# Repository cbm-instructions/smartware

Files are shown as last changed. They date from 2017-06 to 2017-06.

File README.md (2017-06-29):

# Smartware
"Challenge Based Making" an der Hochschule Mannheim im Sommersemester 2017. Betreut von Prof. Thomas Smits und Prof. Kirstin Kohler.
Die Projektarbeit dieses Kurses fand in zwei Pfasen statt: Dem Design Thinking und der Umsetzung.

# Übersicht
* [POV](#pov)
* [Lösungsansatz/Prototyp](#lösungsansatzprototyp)
	* [Konzept](#konzept)
* [(Bau-)Anleitung](#bau-anleitung)
	* [Laserschranke](#laserschranke)
		* [Schranken](#schranken)
		* [Elektronik](#elektronik)
			* [Schaltplan](#schaltplan)
			* [Code](#code)
	* [Webkomponente](#webkomponente)
		* [Frontend](#frontend)
		* [Backend](#backend)
	* [Messstation](#messstation)
		* [Schaltplan](#schaltplan-1)
		* [Code](#code-1)
* [Fazit](#fazit)

## POV
_Wie können wir Stundenten helfen freie Räume zu finden, um dort in Ruhe zu lernen/arbeiten?_

## Lösungsansatz/Prototyp
Da es an unserer Hochschule keine zentrale Übersicht über aktuelle Raumbelegungen gibt und somit die Suche nach freien Hörsälen zum (gemeinsamen) Lernen und Arbeiten mitunter zeitaufwändig werden kann, wollten wir ein System entwickeln, mit dem Studenten überall und jederzeit geeignete Lernräume finden können.
Zu diesem Zweck haben wir ein dreiteiliges System entwickelt, bestehend aus:
*	Türsystem
	*	Laserschranke
	*	Türsensor (Reed Switch)
*	Webkomponente
*	Messstation

Das Türsystem erfasst Aktivität im Eingangsbereich. Während die Laserschranke bei Unterbrechung des Laserstrahls durch dadurch laufende Menschen auslöst, registriert der Türsensor das Öffnen und Schließen der Tür. Die Messstation misst die Temperatur- und Luftfeuchtigkeit, um eine Bewertung der Luftqualität zu ermöglichen. All diese Daten fließen in der Webkomponente zusammen. Diese kann auf mobilen sowie Desktop-Geräten genutzt werden.

## (Bau-)Anleitung
### Laserschranke
Folgende Teile benötigt (Angaben in mm):
*   2 x OSB-Platte (800 x 150 x 10), als vertikale Halterung
*   2 x Holzplatte (350 x 150 x 30), aus möglichst schwerem Holz
*   2 x Dachlatte 360mm lang, als zusätzliche Befestigung -
	Diese müssen an beiden Enden auf Gehrung gesägt werden, sodass diese als Diagonale, zwischen Bodenplatte und vertikaler OSB-Platte, verwendet werden können.
*   2 x Dachlatte 70mm lang, als Spiegelhalterung -
	Diese müssen an einem Ende auf Gehrung gesägt werden, sodass die Spiegel im 45 Grad Winkel angebracht werden können.
*   2 x Schminkspiegel
*   Diverse Holzschrauben
*   Optional: Lack in beliebiger Farbe
*   Optional: Zur besseren Befestigung des Lasers, sowie des Fototransistors können Winkel eingesetzt werden.

Laserhalterung
Spiegelhalterung

Die Halterungen werden wie auf den Bildern zu sehen, zusammengeschraubt und falls gewünscht mit dem Lack besprüht. An der rechten Halterung ist ein Metwallwinkel zu sehen. Dieser wurde an der Oberseite mit etwas Klebeband isoliert, damit er keinen Kurzschluss erzeugt. Darauf wird später der Laser montiert. An der anderen Halterung muss dann die Spiegelhalterung (Dachlatten 70mm lang) angeschraubt werden. In einigem Abstand darunter wird die zweite Spiegelhalterung montiert. Die Spiegel werden dann mit Heißkleber befestigt. 
Funktionsweise: Der Laser schießt das Licht auf den oberen Spiegel, welcher das Licht auf den unteren reflektiert und anschließend wieder zurück zur anderen Halterung. An der Stelle, wo der Laser wieder auftrifft wird dann der Fototransistor befestigt, sodass erkannt werden kann, ob der Lichtstrahl unterbrochen wurde.

**Bitte beachten Sie:**
Diese Halterungen waren nur für den Prototyp gedacht. Wenn das System dauerhaft installiert werden soll, ist eine feste Verankerung (bspw. im Türrahmen) sinnvoll.

#### Elektronik
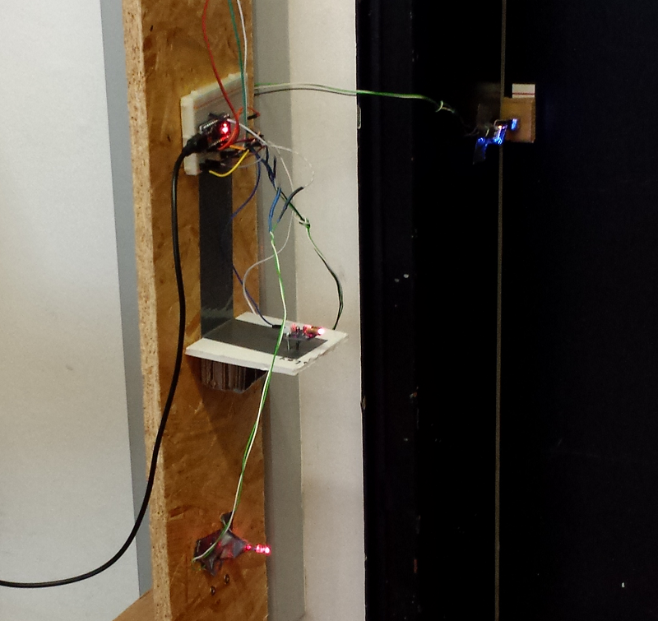
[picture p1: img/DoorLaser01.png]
DoorLaser


##### Schaltplan
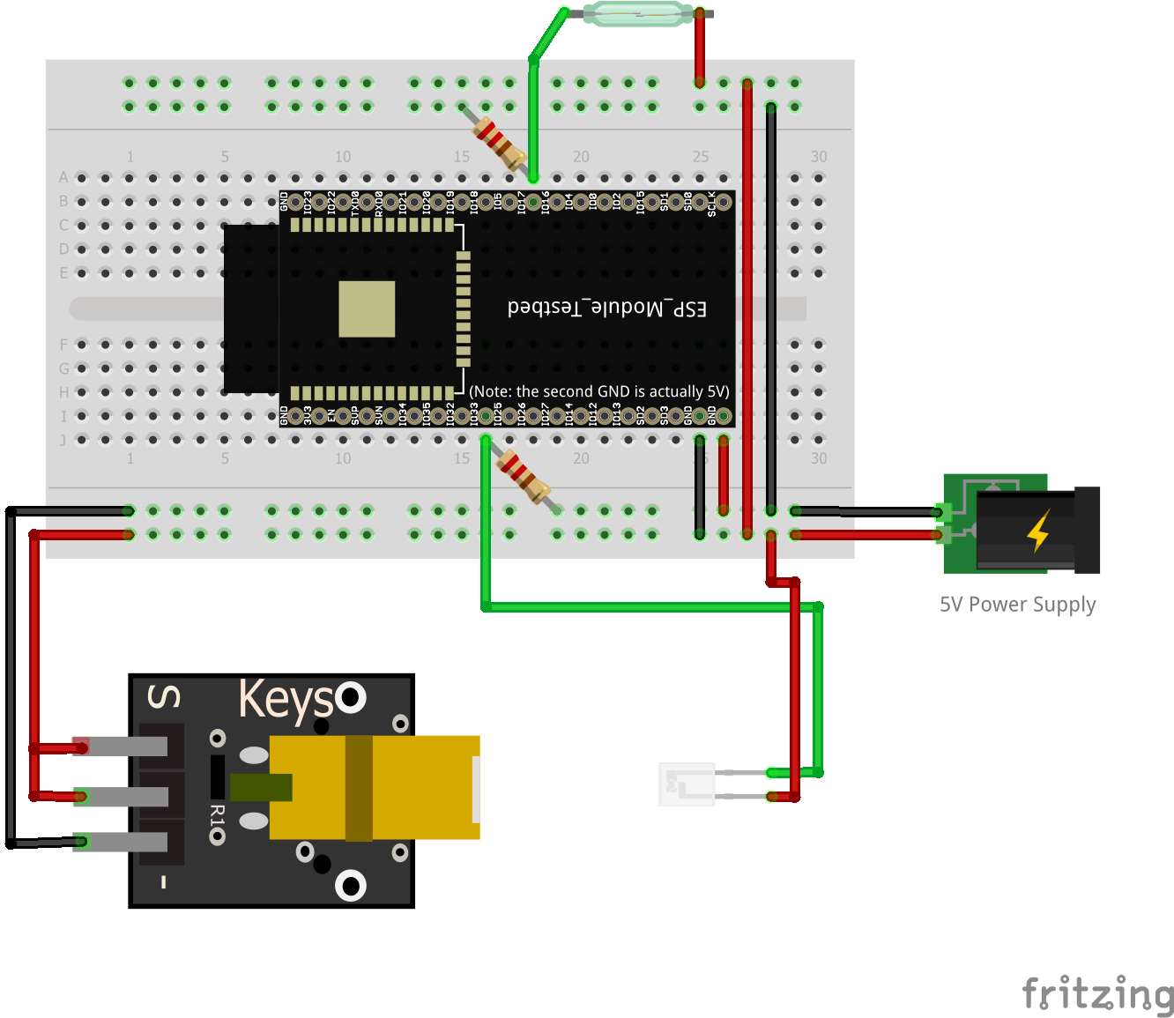
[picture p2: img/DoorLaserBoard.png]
Schaltplan DoorLaser

Bauteile:
* [ESP32](https://www.aliexpress.com/store/product/ESP32-Development-Board-WiFi-Bluetooth-Ultra-Low-Power-Consumption-Dual-Cores-ESP-32-ESP-32S/1983387_32799057508.html)
* 2x4.7k Ohm Widerstände
* [Phototransistor](https://www.conrad.de/de/fototransistor-5-mm-1100-nm-everlight-opto-pt331cpt333-3c-156408.html)
* [Laser](https://www.amazon.de/SunFounder-Transmitter-Sensor-Arduino-Raspberry/dp/B013QSHMSU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)
* Reed-Schalter
* Externe Stromversorgung 5V, min. 500mA

Der Reed-Schalter wird in diesem Beispiel an Pin 17, der Phototransistor an Pin 33 angeschlossen - Diese Pinbelegung wird auch im Code verwendet!

##### Code
Der Source-Code für die Laserschranke befindet sich unter [/src/DoorLaser/](/src/DoorLaser/). Die WLAN-Funktionalität inkl. Webserver sind [arduino-esp32 - SimpleWiFiServer](https://github.com/espressif/arduino-esp32/blob/master/libraries/WiFi/examples/SimpleWiFiServer/SimpleWiFiServer.ino) entnommen.

Wir haben, um das Hauptprogramm einfach zu halten, Klassen erstellt, die uns erlauben, bequem [digitale](/src/DoorLaser/DigitalListener.h) und [analoge](/src/DoorLaser/AnalogListener.h) Pins zu überwachen und deren Auslösungen zu zählen.

**Achtung:** Der ESP32 verwendet 12Bit ADCs, was bedeutet, dass analoge 5V-Signale anstatt des auf Arduinos üblichen Wertebereiches von 0-255 auf 0-4095 gemappt werden. 

### Webkomponente

#### Frontend

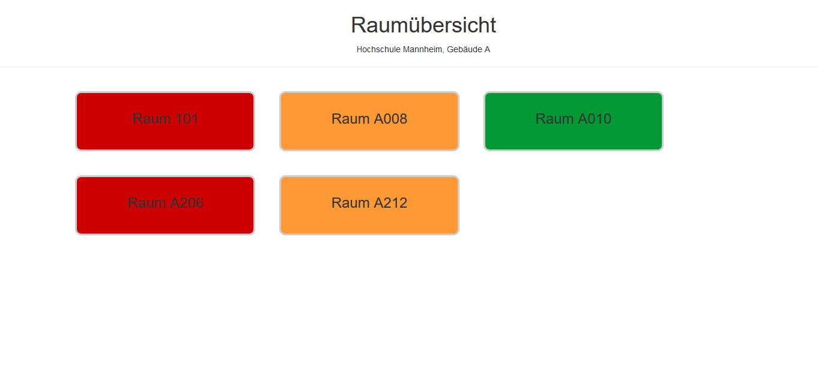
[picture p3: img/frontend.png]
Frontend

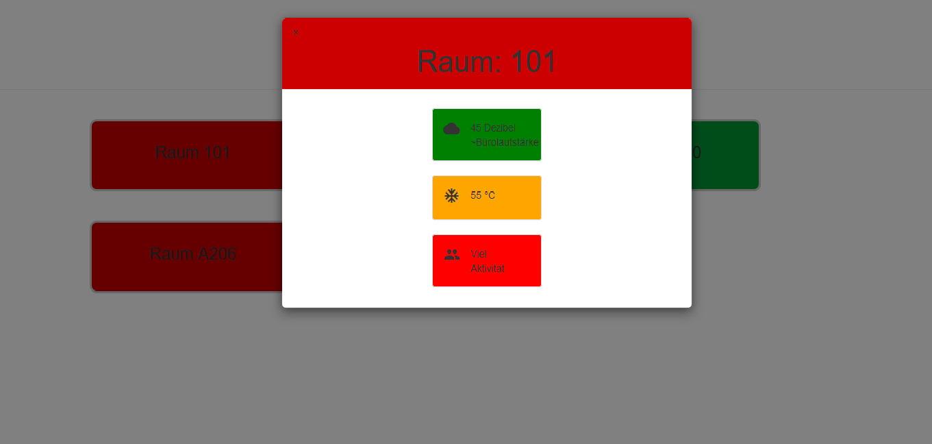
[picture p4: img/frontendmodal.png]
Frontend_Modal


Hier befindet sich die Benutzeroberfläche, welche mit HTML und CSS realisiert wird.
Außerdem sind Bootstrap und die Material-Icons von Google im Einsatz.

#### Backend

Hier befindet sich der Code zum betreiben des Backend Servers.
Geschrieben in node.js. Außerdem wird eine mysql Datenbank genutzt.

##### Setup und Installation des Backend und Frontend auf dem Raspberry Pi 

###### Benötigte Teile: 
	Raspberry Pi 3
	Micro SD Karte
	Router mit Internetverbindung (Internet nur zur Konfiguration)
	USB-Maus, USB Tastatur, Netzadapter Micro-USB, HDMI-fähiger Monitor

###### Installieren sie Raspbian auf dem Raspberry Pi.
	Eine einfache Schritt für Schritt Anleitung ist hier zu finden: 
	https://www.raspberrypi.org/learning/noobs-install/
	
###### Verbinden sie den Raspberry mit dem Internet.

###### Installieren der benötigten Software.
	Führen sie folgende Befehle in der Konsole aus:
	sudo apt-get update
	sudo apt-get upgrade

	Folgende Befehle installieren einen Datenbank-Server:
	sudo apt-get install mysql-server
	sudo apt-get install mysql-client
	sudo service mysql start;
	
	Installieren von git:
	sudo apt-get install git
	
	Installieren von nodejs:
	In einem leeren Verzeichnis:
	sudo git clone https://github.com/creationix/nvm.git.nvm

	Bitte folgenden Code an das Ende dieser Datei hängen: ~/.bashrc
	(Öffnen mit: sudo nano ~/.bashrc)
	export NVM_DIR="$HOME/.nvm"
	[ -s "$NVM_DIR/nvm.sh" ] && . "$NVM_DIR/nvm.sh"
	
	In der Konsole node und npm installieren:
	nvm install node
	nvm install npm

	prüfe installation mit:
	node --version 
	npm --version

###### Anlegen der Datenbank
	Einloggen in den Datenbank-Server mit:
	mysql -u „adminname“ -p -h localhost
	Anschließend das bei der Installation vergebene Passwort eingeben.
	
	In der mysql konsole (angezeigt durch mysql> folgende Befehle eingeben:
	
	create Database cbm;
	use cbm;
	
	create table rooms(room_id int NOT NULL auto_increment,
	name varchar(20) NOT NULL ,PRIMARY KEY(room_id));
	
	create Table sensors(sensor_id int NOT NULL auto_increment, 
	name varchar(20) NOT NULL, type varchar(20) NOT NULL,
	url varchar(200) NOT NULL, room_id int  NOT NULL, PRIMARY KEY(sensor_id), 
	FOREIGN KEY(room_id) references rooms(room_id));
	
	create table sensorvalues(value_id int NOT NULL auto_increment, 
	sensor_id int NOT NULL, value int NOT NULL, timest timestamp ,
	PRIMARY KEY(value_id),FOREIGN KEY(sensor_id) references sensors(sensor_id));

	Räume und Sensoren in die Datenbank eintragen:
	In der mysql Konsole:
	insert into rooms(name) values(„name“);
	
	Eingabe für jeden Raum wiederholen.

	Die zugeordneten Ids können nun mit folgender Eingabe angezeigt werden:
	Select * from rooms;

	Anschließend Sensoren in DB eintragen:
	Insert into sensors(room_id,name,type,url) values(„raum_id“,“name“,“typ“,“url“);
	
	Id muss richtigem Raum zugeordnet sein.
	Name ist frei wählbar.
	Typ muss entweder „temp“, „vol“ oder „light“ sein.
	In url muss die URL-Adresse eingetragen werden unter der der Sensor erreichbar ist.

###### Herunterladen und starten des Servers
	In leerem Ordner:
	sudo git clone https://github.com/cbm-instructions/smartware.git
	
	Die Datei mymysql.js öffnen und Adminname und Passwort des Datenbank-Servers eintragen.
	sudo nano src/WebComponent/backend/mymysql.js	

	Installieren der Abhängigkeiten:
	Im Verzeichnis src/webComonent ausführen:
	npm install 
	
	Nun kann der Code gestartet werden: 
	node main.js

	Der Server sollte nun unter seiner IP-Adresse auf Port 3000 erreichbar sein.
	(anzeigbar durch den Befehl ifconfig)

### Messstation
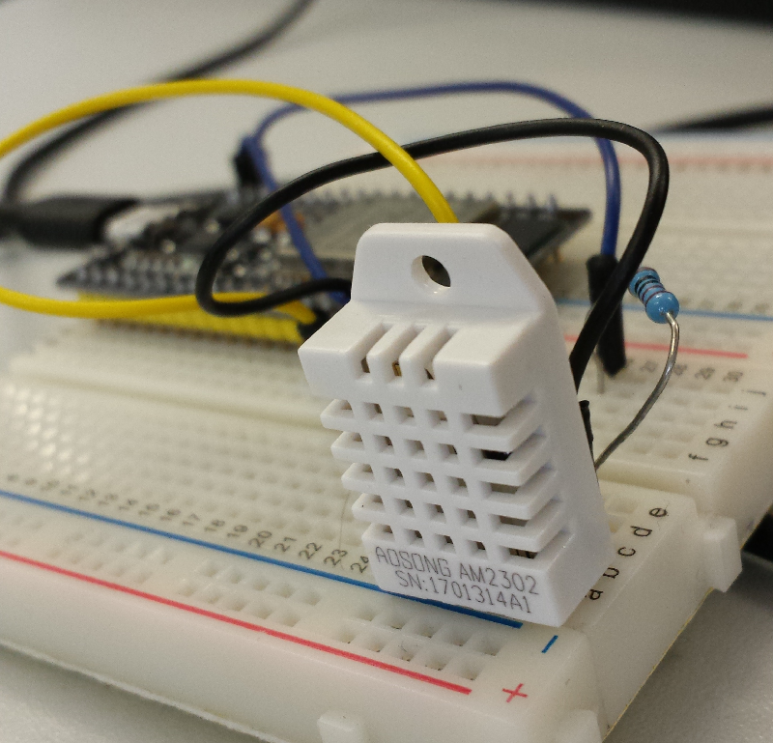
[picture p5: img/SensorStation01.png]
Messstation


#### Schaltplan
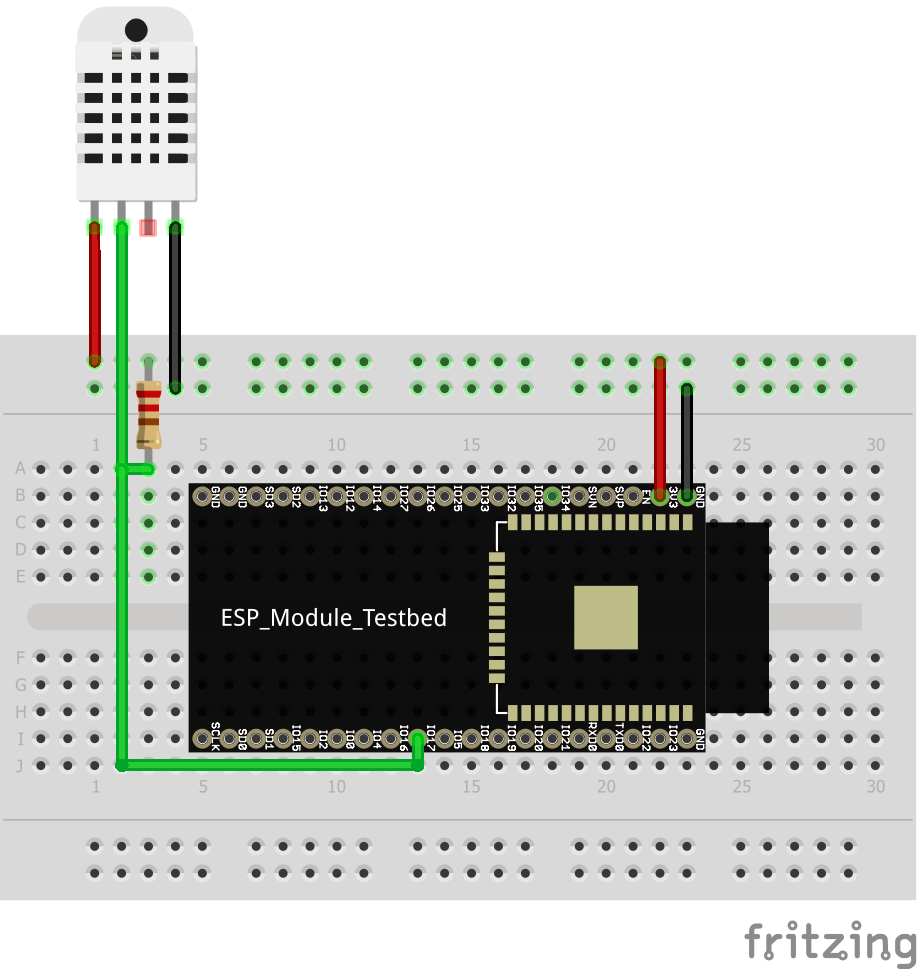
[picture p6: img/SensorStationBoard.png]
Schaltplan SensorStation

Bauteile:
* [ESP32](https://www.aliexpress.com/store/product/ESP32-Development-Board-WiFi-Bluetooth-Ultra-Low-Power-Consumption-Dual-Cores-ESP-32-ESP-32S/1983387_32799057508.html)
* 4.7k Ohm Widerstand
* [DHT22](https://www.aliexpress.com/item/50PCS-LOT-DHT22-AM2302-Digital-Temperature-and-Humidity-Sensor-DHT22-Free-shiping/1699337492.html)
* Micro-USB Kabel direkt am ESP32 für Stromversorgung

Pin 1 des DHT22 wird mit VCC, Pin 4 mit Masse und Pin 3 gar nicht verbunden. Pin 2 wird mit einem digitalen IO-Pin und über einen 4.7k Ohm Widerstand mit VCC verbunden.

#### Code
Der Source-Code für die Messstation befindet sich unter [/src/SensorStation/](/src/SensorStation/). Die WLAN-Funktionalität inkl. Webserver sind [arduino-esp32 - SimpleWiFiServer](https://github.com/espressif/arduino-esp32/blob/master/libraries/WiFi/examples/SimpleWiFiServer/SimpleWiFiServer.ino) entnommen. Backend und Frontend Code befinden sich unter
(src/WebComponent)

Wir hatten im Verlauf des Projekts Probleme damit, den DHT22 stabil durch den ESP32 anzusteuern. Deswegen haben wir uns dazu entschieden, fehlerhafte Messwerte zu ignorieren und nur die aktuellsten ([korrekten](/src/SensorStation/SensorStation.ino#L58)) Messwerte an das Backend weiterzureichen. Unsere Tests haben ergeben, dass ungefähr 80% aller Messungen fehlerhaft sind - Das kompensieren wir durch häufige (sekündliche) Messungen.

## Fazit

Die vorhandenen Daten lassen zwar bereits eine recht gute Bewertung der Raumverfügbarkeiten zu, jedoch würden Lautstärkemessungen die Qualität der Beurteilungen deutlich erhöhen. Aus Nutzerinterviews ging hervor, dass besonders die mobile Anwendung viel Anklang finden würde. Die Verwendung von WLAN als Kommunikationskanal resultierte in einfachen Installationen, verglichen mit kabelgebundenen Lösungen.

Bezüglich der Erweiterung des Sytems um Lautstärkemessungen muss recherchiert und erarbeitet werden, welche Mikrofone sich für diesen speziellen Anwendungsfall eignen. Für eine dauerhafte Installation der Türstation empfehlen wir die feste Integration der Bauteile in Türrahmen. Die Messstation hingegen kann frei im Raum platziert werden. Zur präziseren Bewertung der Luftqualität könnten verschiedene Bestandteile in der Raumluft gemessen werden.

Das positive Feedback der Nutzer, der unkomplizierte Zusammenbau und die einfache Installation der Komponenten legen die Umsetzung des Projekts an der Hochschule nahe. Ebenso bietet es viele Möglichkeiten zur Erweiterung und kann beispielsweise für Open Data über die Hochschule verwendet werden.

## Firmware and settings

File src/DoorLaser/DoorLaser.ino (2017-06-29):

/*
  Based on "WiFi Web Server LED Blink"-example 
*/

#include <WiFi.h>
#include "AnalogListener.h"
#include "DigitalListener.h"

#define PIN_DOOR 17
#define PIN_LASER 33
#define LASER_MIN 1024 //anstatt 300: ESP32 hat 12bit ADC!
#define LASER_MAX 4095 //anstatt 1024: ESP32 hat 12bit ADC

const char* ssid     = "YOUR_SSID";
const char* password = "YOUR_PASSWORD";

WiFiServer server(80);
AnalogListener laser(PIN_LASER, LASER_MIN, LASER_MAX);
DigitalListener door(PIN_DOOR, LOW);
char json[256];

void setup() {
    Serial.begin(115200);

    // We start by connecting to a WiFi network

    Serial.println();
    Serial.println();
    Serial.print("Connecting to ");
    Serial.println(ssid);

    WiFi.begin(ssid, password);

    while (WiFi.status() != WL_CONNECTED) {
        delay(500);
        Serial.print(".");
    }

    Serial.println("");
    Serial.println("WiFi connected");
    Serial.println("IP address: ");
    Serial.println(WiFi.localIP());
    
    server.begin();
}

void writeJson() {
  sprintf(json, "{\"uptime\":%lu,\"laser\":%i,\"door\":%i}", millis(), laser.GetCountTriggered(), door.GetCountTriggered());
}

void loop() {  
  laser.Update();
  door.Update();

  WiFiClient client = server.available();   // listen for incoming clients
  if (client) {                             
    Serial.println("new client");           
    while (client.connected()) {            
      while (client.available()) 
        client.read();

      writeJson();
      laser.Reset();
      door.Reset();
      Serial.println(json);
      client.print(json);
      break;
    }
    // close the connection:
    client.stop();
    Serial.println("client disonnected");
  }
  
}

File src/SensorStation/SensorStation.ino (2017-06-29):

/*
  Based on "WiFi Web Server LED Blink"-example 
*/

#include <WiFi.h>
#include <DHT.h>
#define DHTTYPE DHT22
#define DHTPIN  17

const char* ssid     = "YOUR_SSID";
const char* password = "YOUR_PASSWORD";
WiFiServer server(80);
DHT dht(DHTPIN, DHTTYPE, DHTPIN);
 
float humidity, temp_f;  // Values read from sensor
char json[256];
unsigned long previousMillis = 0;        // will store last temp was read
const long interval = 1000;              // interval at which to read sensor
bool error = false;

void setup()
{
    Serial.begin(115200);

    // We start by connecting to a WiFi network

    Serial.println();
    Serial.println();
    Serial.print("Connecting to ");
    Serial.println(ssid);

    WiFi.begin(ssid, password);

    while (WiFi.status() != WL_CONNECTED) {
        delay(500);
        Serial.print(".");
    }

    Serial.println("");
    Serial.println("WiFi connected");
    Serial.println("IP address: ");
    Serial.println(WiFi.localIP());
    
    server.begin();

    dht.begin();           // initialize temperature sensor
}
 
void gettemperature() {
  unsigned long currentMillis = millis();
 
  //Perform updates in fixed intervals
  if (currentMillis - previousMillis >= interval) {
    previousMillis = currentMillis;
    float _humidity = dht.readHumidity();
    float _temp_f = dht.readTemperature(false);
    error = isnan(_humidity) || isnan(_temp_f);
    if (!error) {
      //Save measures if they were read correctly
      humidity = _humidity;
      temp_f = _temp_f;
    }
  }
}

void writeJson() {
  char txtTemp[16] = {0};
  char txtHum[16] = {0};
  dtostrf(temp_f, 3, 2, txtTemp);
  dtostrf(humidity, 3, 2, txtHum);
  sprintf(json, "{\"uptime\":%lu,\"error\":%i,\"temp\":%s,\"humidity\":%s}", millis(), (int)error, txtTemp, txtHum);
}


void loop(){
  gettemperature();
  WiFiClient client = server.available();   // listen for incoming clients
  if (client) {                             
    Serial.println("new client");           
    while (client.connected()) {            
      while (client.available()) 
        client.read();

      writeJson();
      Serial.println(json);
      client.print(json);
      break;
    }
    // close the connection:
    client.stop();
    Serial.println("client disonnected");
  }
}

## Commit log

2017-06-29 Added fritzing-sketches
    [DoorLaser.fzz, SensorStation.fzz]
2017-06-29 Added documentation for DoorLaser and SensorStation
